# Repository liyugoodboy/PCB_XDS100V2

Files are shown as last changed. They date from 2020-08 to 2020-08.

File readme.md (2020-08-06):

# XDS100V2Emu

TI DSPC2000系列调试器XDS100V2 PCB工程

### 说明

原理图参照LAUNCHPADF28379D上的调试器部分电路，把FT2232芯片的封装换成LQFP64，更便于手动焊接。PCB工程使用的AD19绘制，在XDS100V2Emu文件中，包含两个PCB文件XDS100V2Emu.PcbDoc和XDS100V2EmuMini.PcbDoc。XDS100V2Emu.PcbDoc为接口带有隔离芯片的PCB(可不焊接隔离芯片)，XDS100V2EmuMini.PcbDoc是去掉隔离芯片，只有FT2232芯片的PCB。

MProg 3.5 Release.rar：给FE2232的EEPROM烧写配置信息的软件。

XDS100V2.ept：给软件MProg使用烧写软件。

注：PCB已完成制板并调试成功，完全实现LAUNCHPAD上的调试器功能。

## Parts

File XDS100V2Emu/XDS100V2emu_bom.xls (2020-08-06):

Comment | Part Number | Description | Designator | Footprint | Quantity
10µF |  | CAP CER 10UF 16V X7R 0805 | C1, C2 | CAP 0805_2012 | 2
0.1µF |  | CAP CER 0.1UF 16V X7R 0603 | C3,C6,C7,C10 | CAP 0603_1608 | 1
4.7uF |  | CAP,4.7UF,+/-20%,X5R,6.3V,SMD0603 | C4, C5 | CAP 0603/1608 | 2
3.3uF |  | CAP,3.3uF,+/-10%,X5R,10V,SMD0603 | C9 | CAP 0603/1608 | 1
8pF |  | CAP,8pF,+/-5%,C0G,16V,SMD0603 | C11, C12 | CAP 0603/1608 | 2
JTAG |  | Header, 14-Pin | CN1 | JTAG调试接口 | 1
Red | SML-LXFM0603SIC-TR | LED RED CLEAR 0603 SMD | D1 | LED 0603_1608 RED | 1
Yellow | SML-D12Y8WT86 | LED YELLOW DIFFUSED 0603 SMD | D2 | LED 0603_1608 YELLOW | 1
Green | SML-D13FWT86 | LED GREEN DIFFUSED 0603 SMD | D3 | LED 0603_1608 GREEN | 1
MF-MSMF050-2 | MF-MSMF050-2 | PTC RESETTABLE .50A 15V 1812 | F1 | FUSM4632X85N | 1
470 Ohms @ 100MHz | BLM18BB471SN1D | FERRITE BEAD 470 OHM 0603 1LN | FB1, FB2 | FER 0603_1608 | 2
USB Micro | 10118193-0001LF |  | J1 | FCI USB 10118193-0001LF | 1
680R |  | RES,680R,+/-5%,1/10W,SMD0603 | R1, R13, R18 | RES 0603/1608 | 3
0R |  | RES,0R,+/-5%,1/10W,SMD0603 | R2, R3, R4,R19,R20 | RES 0603/1608 | 3
NOT_INSTALLED |  | RES,0R,+/-5%,1/10W,SMD0603 | R5, R6, R7, R8, R15, R16, R17 | RES 0603/1608 | 7
1K |  | RES,1K,+/-5%,1/10W,SMD0603 | R9, R10 | RES 0603/1608 | 2
12K |  | RES,12K,+/-1%,1/10W,SMD0603 | R11 | RES 0603/1608 | 1
10K |  | RES,10K,+/-1%,1/10W,SMD0603 | R12 | RES 0603/1608 | 1
2K2 |  | RES,2K2,+/-1%,1/10W,SMD0603 | R14 | RES 0603/1608 | 1
FT2232HQ-REEL |  | IC,Dual High Speed USB to Multipurpose UART/FIFO IC,FT2232HL-REEL,LQFP-64,SMD | U1 | LQFP64_N | 1
ISO7240CDWR |  | IC DGTL ISO 4CH CMOS 16SOIC,CUSTOMER SUPPLY | U2 | SOIC127P1030X265-16N | 1
ISO7231CDWR |  | IC DGTL ISO 3CH CMOS 16SOIC,CUSTOMER SUPPLY | U3 | SOIC127P1030X265-16N | 1
93LC56BT-I/OT |  | IC,EEPROM Serial-Microwire 2K-Bit 128 x 16 2MHz,93LC56BT-I/OT,SOT-23-6,SMD | U4 | SOT23-6 | 1
AMS1117-3.3 |  | 电源转换5Vto3.3V | U5 | DIODES SOT-223 | 1
NX3225SA-12MHZ-STD-CSR-6 | NX3225SA-12MHZ-STD-CSR-6 | CRYSTAL 12.0000MHZ 8PF SMD | Y1 | NDK NX3225SA | 1

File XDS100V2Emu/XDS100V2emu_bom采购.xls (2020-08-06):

Comment | Part Number | Description | Footprint | Quantity
10µF |  | CAP CER 10UF 16V X7R 0805 | CAP 0805_2012 | 10
3.3uF |  | CAP,3.3uF,+/-10%,X5R,10V,SMD0603 | CAP 0603/1608 | 10
8pF |  | CAP,8pF,+/-5%,C0G,16V,SMD0603 | CAP 0603/1608 | 10
MF-MSMF050-2 | MF-MSMF050-2 | PTC RESETTABLE .50A 15V 1812 | FUSM4632X85N | 5
470 Ohms @ 100MHz | BLM18BB471SN1D | FERRITE BEAD 470 OHM 0603 1LN | FER 0603_1608 | 10
USB Micro | 10118193-0001LF | FCI连接器 MICRO B型 5针 USB | FCI USB 10118193-0001LF | 3
FT2232HL-REEL | FT2232HL-REEL | IC,Dual High Speed USB to Multipurpose UART/FIFO IC,FT2232HL-REEL,LQFP-64,SMD | LQFP64_N | 3
93LC56BT-I/OT | 93LC56BT-I/OT | IC,EEPROM Serial-Microwire 2K-Bit 128 x 16 2MHz,93LC56BT-I/OT,SOT-23-6,SMD | SOT23-6 | 3
AMS1117-3.3 | AMS1117-3.3 | 电源转换5Vto3.3V | DIODES SOT-223 | 3
NX3225SA-12MHZ-STD-CSR-6 | NX3225SA-12MHZ-STD-CSR-6 | CRYSTAL 12.0000MHZ 8PF SMD | NDK NX3225SA | 3

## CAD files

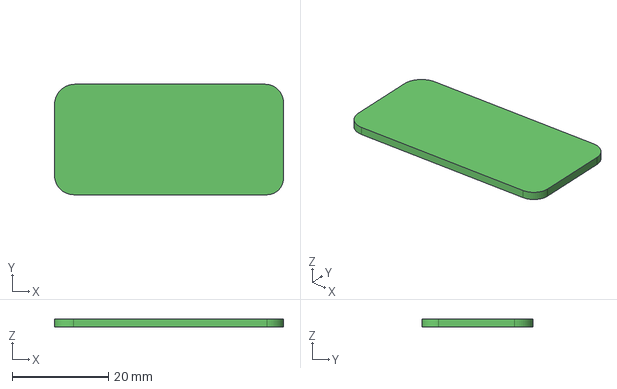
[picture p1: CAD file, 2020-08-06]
XDS100V2Emu/Xds100v2Emu.step
47.6 x 23.0 x 1.62 mm

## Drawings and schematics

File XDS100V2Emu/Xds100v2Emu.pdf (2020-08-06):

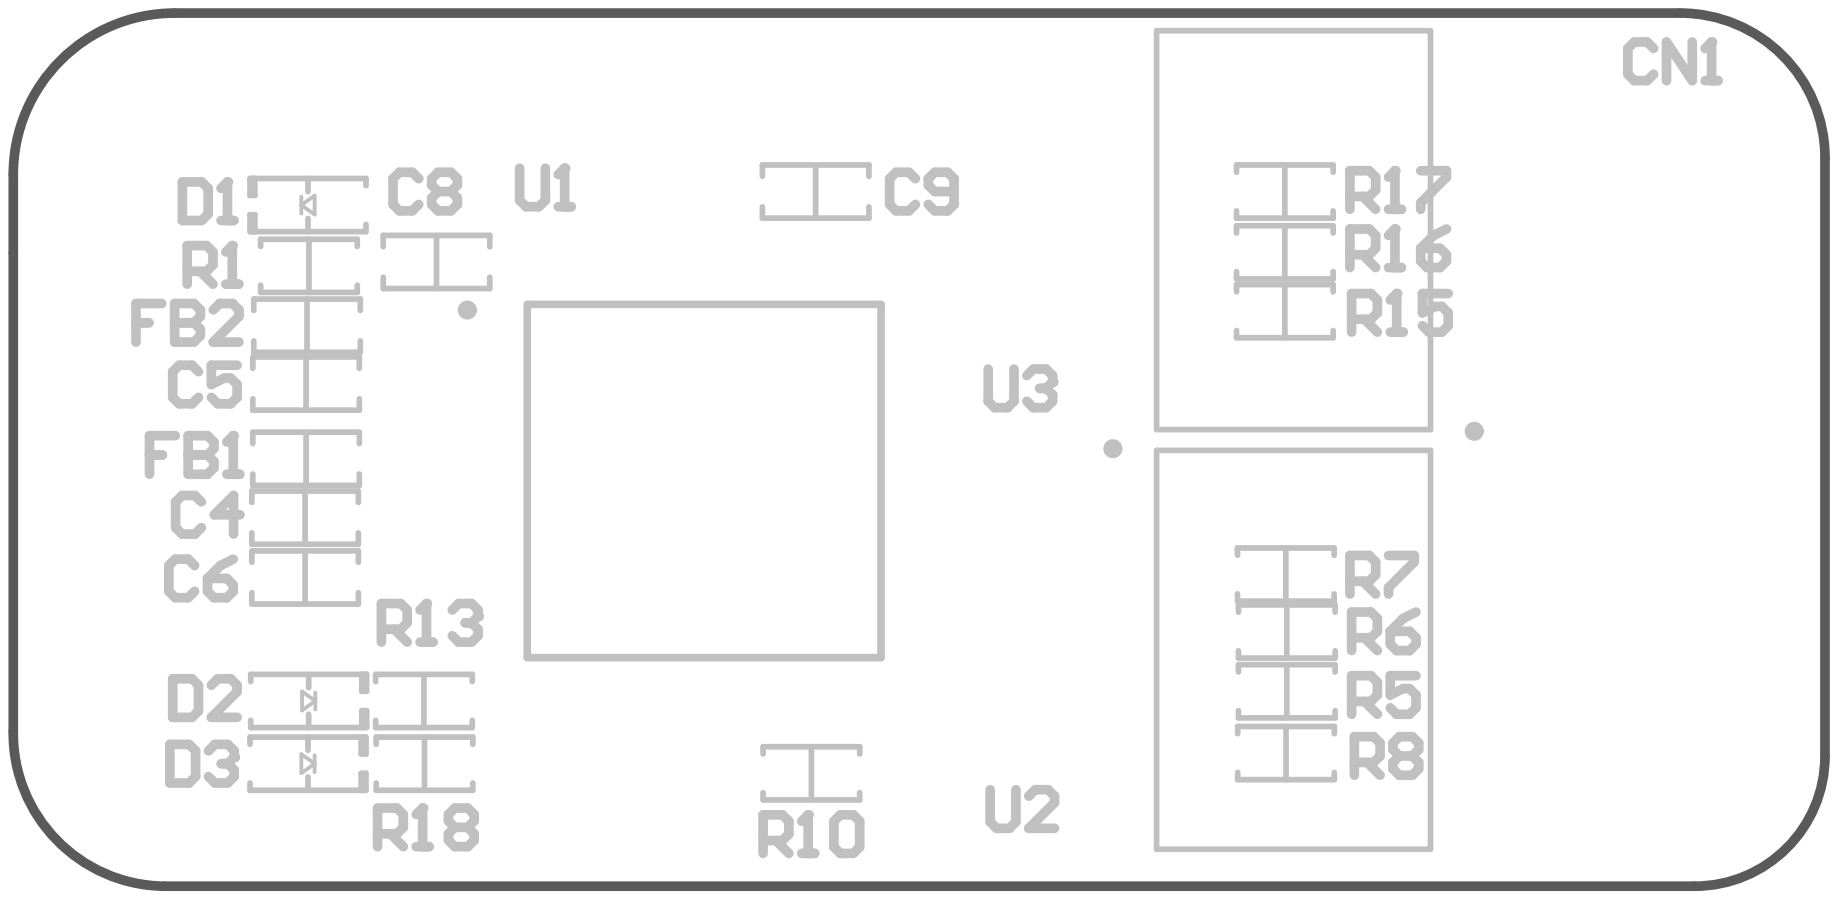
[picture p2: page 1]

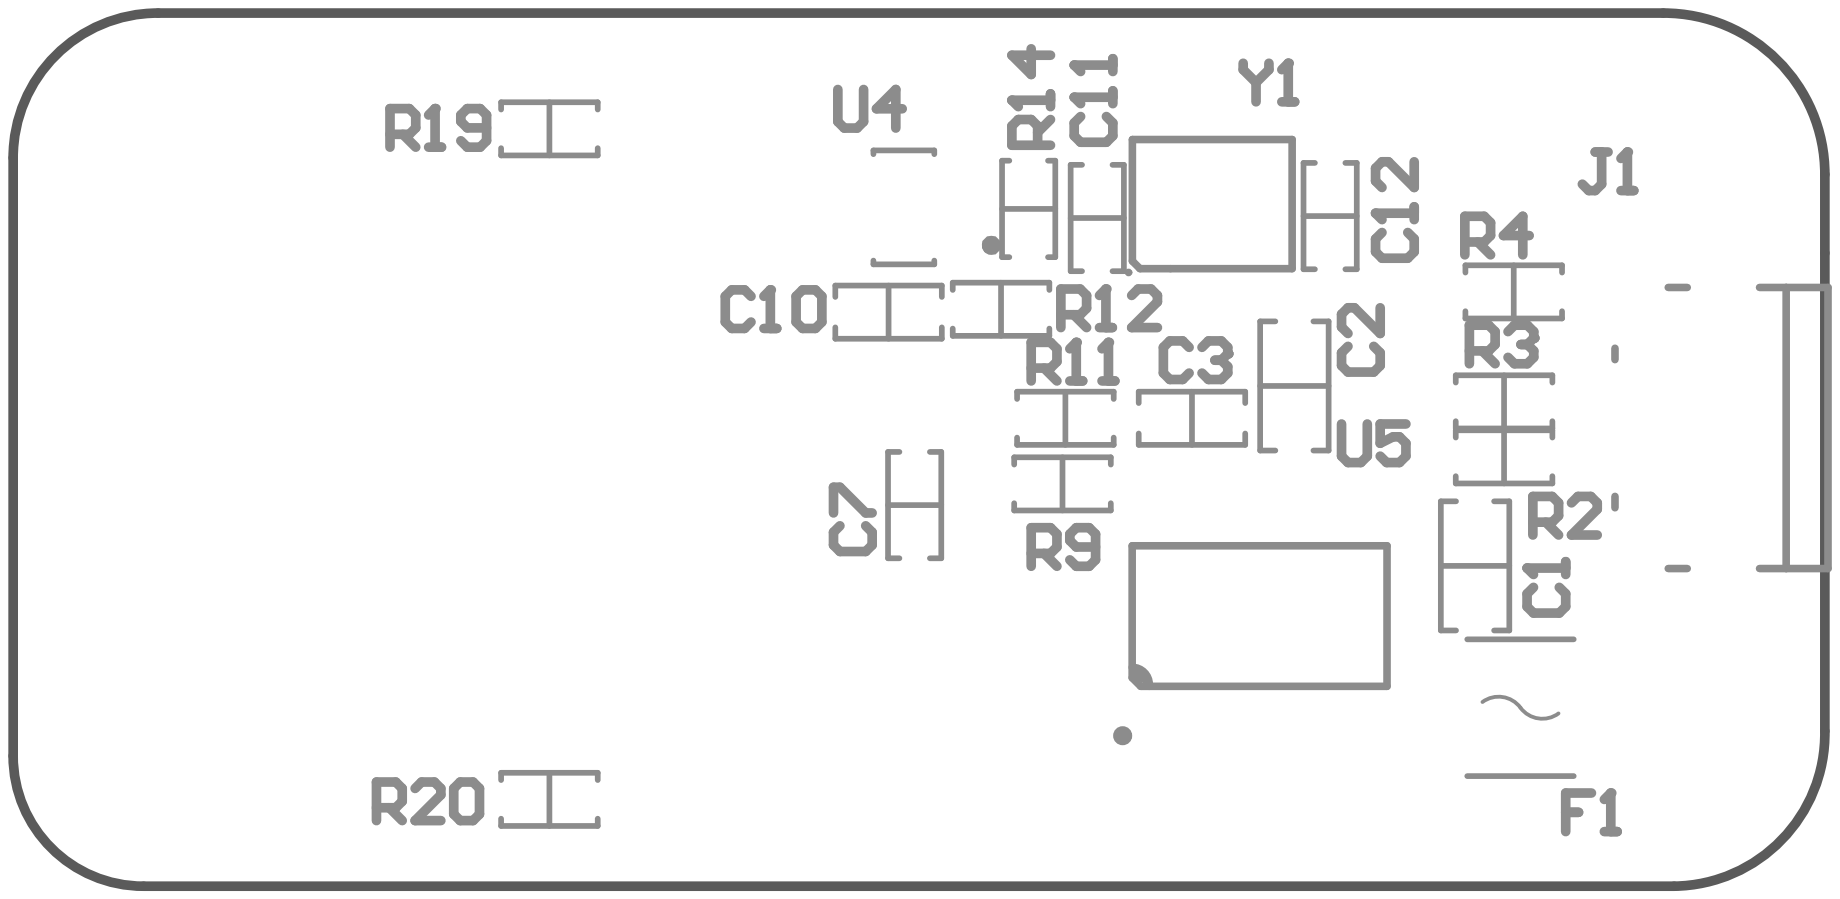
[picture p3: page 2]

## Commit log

2020-08-06 首次提交
    [XDS100V2Emu.PrjPcb, XDS100V2emu_bom.xls, XDS100V2emu_bom采购.xls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]
2020-08-06 更新readme文件
